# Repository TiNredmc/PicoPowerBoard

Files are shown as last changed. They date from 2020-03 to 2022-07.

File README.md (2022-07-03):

# PicoPowerBoard
PicoPower! Simple but yet powerful. the LITTLE TINY development board based on STM8L151F3 mcu

BOMs
=

1. AMS-1117 3v3 x1 // Whatever to 3.3volt DC regulator IC
2. capacitor SMD 0603 100nF x2
3. capacitor SMD 0603 1uF x1
4. CH330 x1 // Super Small USB to Serial. The 1/2 size compare to CH340
5. Pinheader 1x10 x2
6. Push button SMD right angle 
7. STM8L151F3U6 x1
8. MINI usb B female x1
9. PCB from OSHpark (Don't need 2oz copper). : https://oshpark.com/shared_projects/AjHUwVK9

Photos
=

Coming soon.

Design Flaws is in each folder 
=

# Help Me Imporve !

This project is purely Open Source. Help me make it better. Build it your own !

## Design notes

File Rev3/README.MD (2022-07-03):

# Rev3 is out after I left this project untouch for a while(?)

Improvement 
= 

- Better Schematic layout.
- Better Board layout.
- Move CH330N to back side of the board.
- Using smaller reset button.
- removed unnecessary bypass caps.
- USB2.0 Diff pair lenght match and proper routing.

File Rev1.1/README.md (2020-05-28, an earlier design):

# Help Me Improve !

This project is purely Open Source. Grep my design / Make it better / And sell them to me xD (Just kidding).

# Design Flaws (Might be more But this is what I found) 

Since Rev0
The CH330N uses wrong voltage rail (5 volt instead 3.3 volt) this can kill mcu,

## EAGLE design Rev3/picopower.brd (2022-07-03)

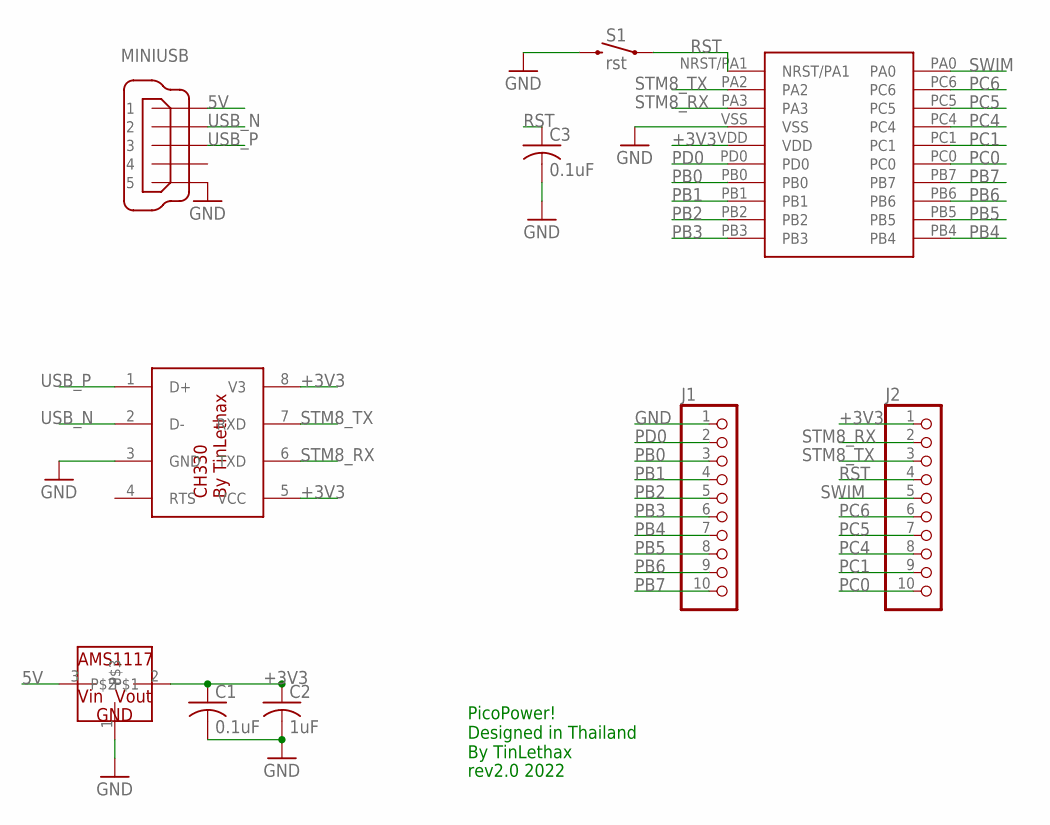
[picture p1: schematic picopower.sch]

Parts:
C1, C3: 0.1uF; C0603K
C2: 1uF; C0603K
IC1: STM8L151F3; UFQFPN-20
IC2: CH330; SOIC127P600X150-8N
IC3: AMS1117; SOT223
J1, J2: PINHD-1X10; 1X10-BIG
MINIUSB: MINI-USB-UX60A-MB-5ST; UX60A-MB-5ST
S1: rst; TACTILE_SWITCH_SMD_RIGHT_ANGLE

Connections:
5V: IC3.3, MINIUSB.1
+3V3: C1.1, C2.1, IC1.VDD, IC2.5 (VCC), IC2.8 (V3), IC3.2, J2.1
GND: C1.2, C2.2, C3.2, IC1.VSS, IC2.3 (GND), IC3.1, J1.1, MINIUSB.5, S1.2
PB0: IC1.PB0, J1.3
PB1: IC1.PB1, J1.4
PB2: IC1.PB2, J1.5
PB3: IC1.PB3, J1.6
PB4: IC1.PB4, J1.7
PB5: IC1.PB5, J1.8
PB6: IC1.PB6, J1.9
PB7: IC1.PB7, J1.10
PC0: IC1.PC0, J2.10
PC1: IC1.PC1, J2.9
PC4: IC1.PC4, J2.8
PC5: IC1.PC5, J2.7
PC6: IC1.PC6, J2.6
PD0: IC1.PD0, J1.2
RST: C3.1, IC1.NRST/PA1, J2.4, S1.1
STM8_RX: IC1.PA3, IC2.6 (TXD), J2.2
STM8_TX: IC1.PA2, IC2.7 (RXD), J2.3
SWIM: IC1.PA0, J2.5
USB_N: IC2.2 (D-), MINIUSB.2
USB_P: IC2.1 (D+), MINIUSB.3

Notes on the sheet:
PicoPower! Designed in Thailand By TinLethax
rev2.0 2022

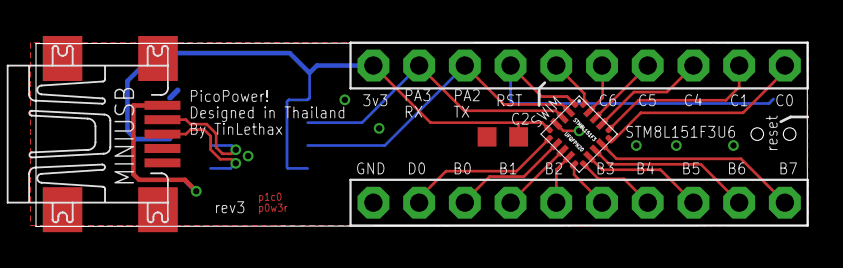
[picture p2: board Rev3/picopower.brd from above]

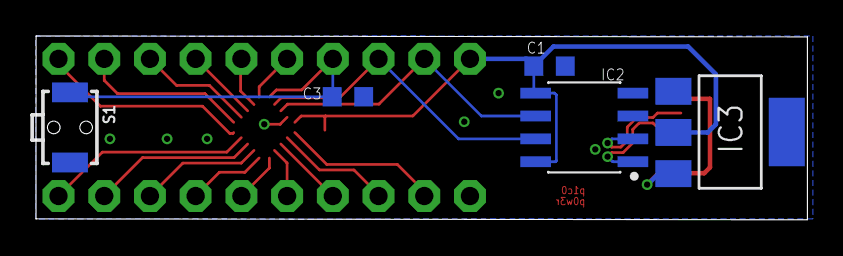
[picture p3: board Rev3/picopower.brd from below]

Board: 2 copper layers, 42.9 x 10.2 mm, 10 parts (5 on the bottom side), 23 nets.

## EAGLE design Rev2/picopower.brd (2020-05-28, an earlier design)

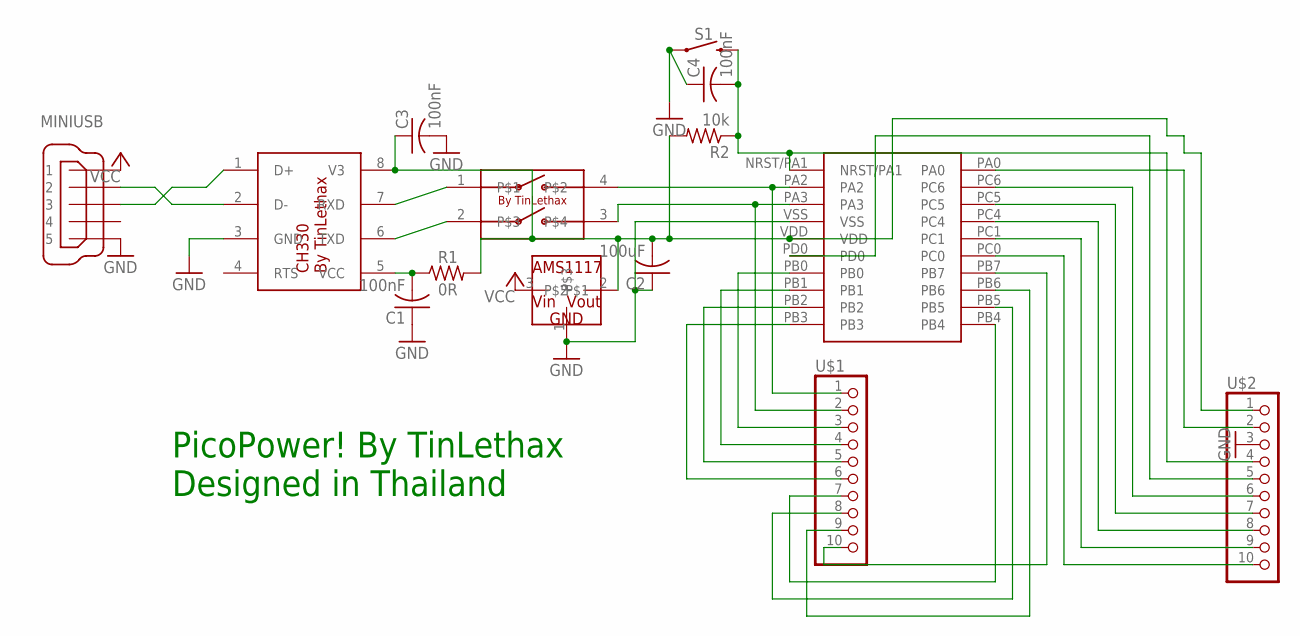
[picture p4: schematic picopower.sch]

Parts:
2DIP: 2DIPSWITCH; SOIC127P835X230-4N
C1, C3, C4: 100nF; C0603K
C2: 100uF; C0603K
CH330: CH330; SOIC127P600X150-8N
MINIUSB: MINI-USB-UX60A-MB-5ST; UX60A-MB-5ST
R1: 0R; R0603
R2: 10k; R0603
S1: MOMENTARY-SWITCH-SPST-SMD-6.0X3.5MM; TACTILE_SWITCH_SMD_6.0X3.5MM
STM8L: STM8L151F3; UFQFPN-20
U$1, U$2: PINHD-1X10; 1X10-BIG
U$3: AMS1117; SOT223

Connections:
GND: C1.1, C2.1, C3.2, C4.1, CH330.3 (GND), MINIUSB.5, S1.1, STM8L.VSS, U$2.3, U$3.1
unnamed: 2DIP.1, CH330.7 (RXD)
unnamed: 2DIP.2, CH330.6 (TXD)
unnamed: 2DIP.4, STM8L.PA2, U$1.1
unnamed: 2DIP.3, STM8L.PA3, U$1.2
unnamed: C1.2, CH330.5 (VCC), R1.1
unnamed: C2.2, C3.1, CH330.8 (V3), R1.2, R2.2, STM8L.VDD, U$2.1, U$3.2
unnamed: STM8L.PB0, U$1.3
unnamed: STM8L.PB1, U$1.4
unnamed: STM8L.PB2, U$1.5
unnamed: STM8L.PB3, U$1.6
unnamed: STM8L.PB4, U$1.7
unnamed: STM8L.PB5, U$1.8
unnamed: STM8L.PB6, U$1.9
unnamed: STM8L.PB7, U$1.10
unnamed: STM8L.PC0, U$2.10
unnamed: STM8L.PC1, U$2.9
unnamed: STM8L.PC4, U$2.8
unnamed: STM8L.PC5, U$2.7
unnamed: STM8L.PC6, U$2.6
unnamed: CH330.2 (D-), MINIUSB.2
unnamed: C4.2, R2.1, S1.2, STM8L.NRST/PA1, U$2.4
unnamed: STM8L.PA0, U$2.2
unnamed: STM8L.PD0, U$2.5
unnamed: CH330.1 (D+), MINIUSB.3
VCC: MINIUSB.1, U$3.3

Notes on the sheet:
PicoPower! By TinLethax Designed in Thailand

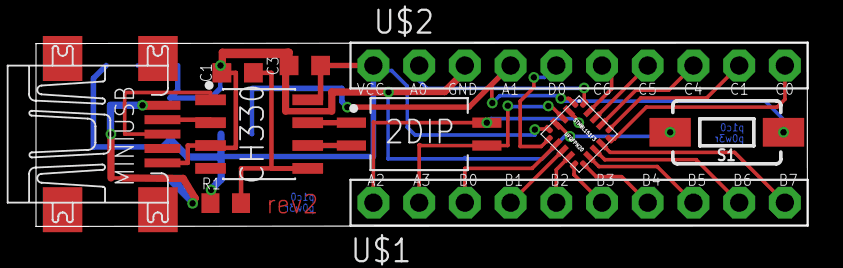
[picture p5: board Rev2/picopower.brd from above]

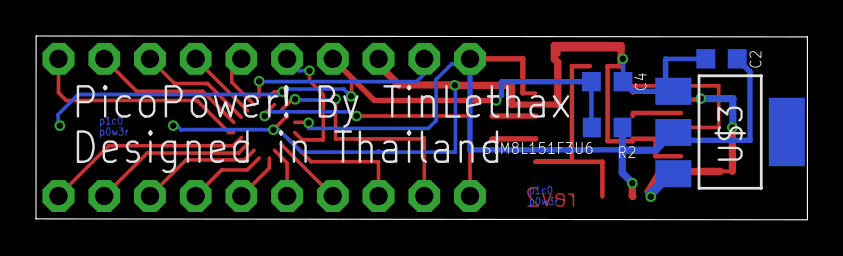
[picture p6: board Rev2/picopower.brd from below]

Board: 2 copper layers, 42.9 x 10.2 mm, 14 parts (4 on the bottom side), 26 nets.

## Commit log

2020-03-18 rev0 schematic and board
    [picopower.brd, picopower.sch]
2020-04-10 rev1 schematic and board
    [picopower.brd, picopower.sch]
2020-04-10 Update OSHpark link to the rev1 Board
2020-05-19 Update link to rev1.1 PCB
2020-05-19 rev1.1 board
    [picopower.brd, picopower.sch]
2020-05-28 update PCB link to rev2 board
2020-05-28 Board and Schematic file
    [picopower.brd, picopower.sch]
2022-07-03 Added Rev3 board and Rev2 schematic
    [picopower.brd, picopower.sch]

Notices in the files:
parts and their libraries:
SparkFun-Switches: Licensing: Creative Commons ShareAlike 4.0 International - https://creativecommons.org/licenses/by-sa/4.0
